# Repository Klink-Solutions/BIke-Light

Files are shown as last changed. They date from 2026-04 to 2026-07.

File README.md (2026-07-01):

# F1® Smart Bike Light

### A universal bike break light designed to improve safety during day and night time operation.

Bike_Light_2026-Apr-03_11-06-38PM-000_CustomizedView57686941933_png

## Description

A F1® rain light inspired bike break light

As an avid biker and lover of F1 I felt why not bring the two together to make me feel a bit faster. While many bikelights that are red and blink do exist; mine does so with function. I found it useful in group rides where you may be caugth off guard by a biker infront of you slowing down. This is where the idea of the adaptive breaklight came into play. Besides the usability for fellow bikers the saftey benifits it provides to you from drivers is enormous. Why do cars need break lights but bikes don't? 

#### Features
  * Adaptive breaking signals your rate of breaking to surrounding drivers and pedestrians 
  * Automatic Day/Night mode
  * Removable for longer battery life and safety
  * Makes your bike look cooler

### Instalation

Mount the bike specific mount to your bikes seat post or bike rack.
The light then securely locks into to the bracket and is easily removable for parking and charging.

* The light automatically goes ito its deepest sleep mode when removed from the bike in this setting this goes it around ~140 (subject to testing) days of operation on a full charge.

* The light automatically adjusts to to local lighting contitions to switch into night mode ( make sure not to cover the sensor for this located at the top to the right of the charging port. 

### Battery life 

* All estimates are subject to testing 

~140 days deep sleep mode

~ 5 hours daytime running

~ 3 hours night time use

## Help

If you are unable to connect the device to your computer to push updates; try holding a magnet near the back to wake up the device from sleep. 

## Authors

Lucas Klemmer  
klinksolutions22@gmail.com

## Version History
* 0.1
    * Initial Release

## Road Map

* Automatic crash detection and warning indicators
* Automatic orientation detection for future features
* Dynamic indicator signals ( might be app controlled but this seems too much of a distraction)
   * If app controlled then potential integration with navigation  

## Repository Contents

This repository contains all components needed for the project:

- CAD files for the housing & universal mount (v2.0) 
- Initial full release code for Bike light 
- Gerber files for PCB manufacturing (v2)
- Supporting project documentation (ReadMe)

## Screenshots




## BOM
[F1 Bike Light-bom.csv](https://github.com/user-attachments/files/26847608/F1.Bike.Light-bom.csv)

<table class="tg"><thead>
  <tr>
    <th class="tg-0lax">Name</th>
    <th class="tg-0lax">Purpose</th>
    <th class="tg-0lax">Quantity</th>
    <th class="tg-0lax">Total Cost (USD)</th>
    <th class="tg-0lax">Link</th>
    <th class="tg-0lax">Distributor</th>
  </tr></thead>
<tbody>
  <tr>
    <td class="tg-0lax">PCBs</td>
    <td class="tg-0lax">$6.30 with current discounts 5 of each of the 2 boards and this price has slow shipping included</td>
    <td class="tg-0lax">10</td>
    <td class="tg-0lax">12.30</td>
    <td class="tg-0lax">https://jlcpcb.com/</td>
    <td class="tg-0lax">JLC PCB</td>
  </tr>
  <tr>
    <td class="tg-0lax">Rechargeable KRL 602030 3.7V 300mAh lithium ion Battery Ultra-Thin 500 Cycles for Wearables IoT Power Tools CE/ KC Certified</td>
    <td class="tg-0lax">Battery</td>
    <td class="tg-0lax">5</td>
    <td class="tg-0lax">6.05</td>
    <td class="tg-0lax">https://www.alibaba.com/product-detail/Rechargeable-KRL-602030-3-7V-300mAh_1600577700959.html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</td>
    <td class="tg-0lax">Alibaba</td>
  </tr>
  <tr>
    <td class="tg-0lax">WP1503SURDK</td>
    <td class="tg-0lax">Ultrabright red LEDs for the main illumination surface</td>
    <td class="tg-0lax">100</td>
    <td class="tg-0lax">13.66</td>
    <td class="tg-0lax">https://www.digikey.ca/en/products/detail/kingbright/WP1503SURDK/16602200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</td>
    <td class="tg-0lax">DigiKey</td>
  </tr>
  <tr>
    <td class="tg-0lax">TEPT4400</td>
    <td class="tg-0lax">Ambient light sensor to enable smart led modes for day vs night time use</td>
    <td class="tg-0lax">5</td>
    <td class="tg-0lax">2.09</td>
    <td class="tg-0lax">https://www.digikey.ca/en/products/detail/vishay-semiconductor-opto-division/TEPT4400/1681191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</td>
    <td class="tg-0lax">Digikey</td>
  </tr>
  <tr>
    <td class="tg-0lax">TLC5927IDBQR</td>
    <td class="tg-0lax">LED driver </td>
    <td class="tg-0lax">5</td>
    <td class="tg-0lax">9.45</td>
    <td class="tg-0lax">https://www.digikey.ca/en/products/detail/texas-instruments/TLC5927IDBQR/1906426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</td>
    <td class="tg-0lax">Digikey</td>
  </tr>
  <tr>
    <td class="tg-0lax">DRV5032FCDBZR</td>
    <td class="tg-0lax">Small SMT bipolar hall effete sensor to act as the wake up for my device</td>
    <td class="tg-0lax">5</td>
    <td class="tg-0lax">1.38</td>
    <td class="tg-0lax">https://www.digikey.ca/en/products/detail/texas-instruments/DRV5032FCDBZR/7173719</td>
    <td class="tg-0lax">DigiKey</td>
  </tr>
  <tr>
    <td class="tg-0lax">ADXL343BCCZ-RL</td>
    <td class="tg-0lax">The main accelerometer ( basically the same as the ADXL 345 i am using for prototyping but with a tiny bit lower sensitivity in exchange for being cheaper) </td>
    <td class="tg-0lax">5</td>
    <td class="tg-0lax">15.87</td>
    <td class="tg-0lax">https://www.digikey.ca/en/products/detail/analog-devices-inc/ADXL343BCCZ-RL/3542841</td>
    <td class="tg-0lax">DigiKey</td>
  </tr>
  <tr>
    <td class="tg-0lax">XIAO ESP32C3</td>
    <td class="tg-0lax">The brains of the break light - Its small size combined with integrated battery charging unit makes it ideal for my application (it is sold in packs of 3 which would be more economical to eventually equip my family with lights of their own </td>
    <td class="tg-0lax">3</td>
    <td class="tg-0lax">13.49</td>
    <td class="tg-0lax">https://www.digikey.ca/en/products/detail/seeed-technology-co-ltd/102010572/24814465</td>
    <td class="tg-0lax">Digikey</td>
  </tr>
</tbody></table>

## License
MIT LIcence

If anyone ends up reproducing this device or making it even bettter I would be happy to see your improvements and add them to the oficial release.

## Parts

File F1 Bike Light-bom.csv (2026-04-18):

Name | Purpose | Quantity | Total Cost (USD) | Link | Distributor
PCBs | $6.30 with current discounts 5 of each of the 2 boards and this price has slow shipping included | 10 | 12.30 | https://jlcpcb.com/ | JLC PCB
Rechargeable KRL 602030 3.7V 300mAh lithium ion Battery Ultra-Thin 500 Cycles for Wearables IoT Power Tools CE/ KC Certified | Battery | 5 | 6.05 | https://www.alibaba.com/product-detail/Rechargeable-KRL-602030-3-7V-300mAh_1600577700959.html | Alibaba
WP1503SURDK | Ultrabright red LEDs for the main illumination surface | 100 | 13.66 | https://www.digikey.ca/en/products/detail/kingbright/WP1503SURDK/16602200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 | DigiKey
TEPT4400 | Ambient light sensor to enable smart led modes for day vs night time use | 5 | 2.09 | https://www.digikey.ca/en/products/detail/vishay-semiconductor-opto-division/TEPT4400/1681191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..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 | Digikey
TLC5927IDBQR | LED driver | 5 | 9.45 | https://www.digikey.ca/en/products/detail/texas-instruments/TLC5927IDBQR/1906426?_gl=1*dl9d99*_up*MQ..*_gs*MQ..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 | Digikey
DRV5032FCDBZR | Small SMT bipolar hall effete sensor to act as the wake up for my device | 5 | 1.38 | https://www.digikey.ca/en/products/detail/texas-instruments/DRV5032FCDBZR/7173719 | DigiKey
ADXL343BCCZ-RL | The main accelerometer ( basically the same as the ADXL 345 i am using for prototyping but with a tiny bit lower sensitivity in exchange for being cheaper) | 5 | 15.87 | https://www.digikey.ca/en/products/detail/analog-devices-inc/ADXL343BCCZ-RL/3542841 | DigiKey
XIAO ESP32C3 | The brains of the break light - Its small size combined with integrated battery charging unit makes it ideal for my application (it is sold in packs of 3 which would be more economical to eventually equip my family with lights of their own | 3 | 13.49 | https://www.digikey.ca/en/products/detail/seeed-technology-co-ltd/102010572/24814465 | Digikey

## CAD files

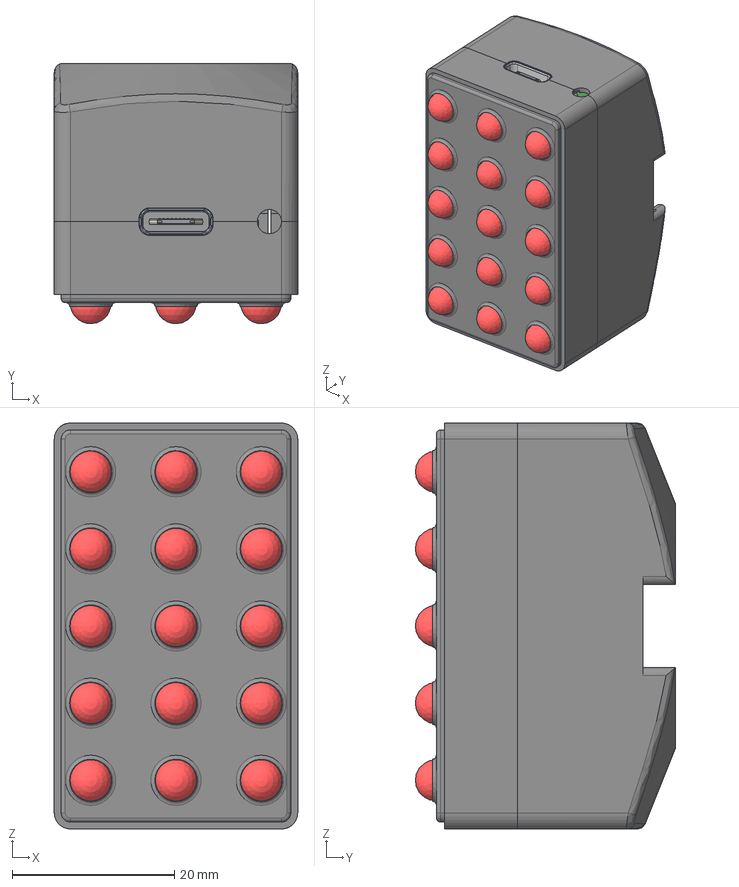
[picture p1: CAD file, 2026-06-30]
CAD/Bike Light case V2.step
30.0 x 32.1 x 50.0 mm
Board
1-copper
64-copper
1-soldermask
64-soldermask
2X08 v2
Board_1
1-copper_1
64-copper_1
1-soldermask_1
64-soldermask_1
9216932.f3d x 5
9216955.f3d
5576557.f3d x 8
JST-2-SMD
BOSS-EXTRUDE14_8_
BOSS-EXTRUDE7_4_
BOSS-EXTRUDE7_3_
BOSS-EXTRUDE14_4_
BOSS-EXTRUDE14_2_
BOSS-EXTRUDE14_11_
BOSS-EXTRUDE7_7_
BOSS-EXTRUDE14_9_
BOSS-EXTRUDE14_3_
BOSS-EXTRUDE14_7_
MIRROR2
BOSS-EXTRUDE14_5_
BOSS-EXTRUDE14_12_
BOSS-EXTRUDE7_8_
BOSS-EXTRUDE7_1_
BOSS-EXTRUDE14_10_
BOSS-EXTRUDE7_9_
BOSS-EXTRUDE14_6_
BOSS-EXTRUDE14_1_
BOSS-EXTRUDE7_6_
BOSS-EXTRUDE7_2_
CUT-EXTRUDE5
BOSS-EXTRUDE7_5_
U.FL Connector v1
Button (1) x 2
Shield
LGA_14 v2
Top Case
93502A111_Symmetrical Heat-Set Inserts for Plastic x 2
Battery
Back Case

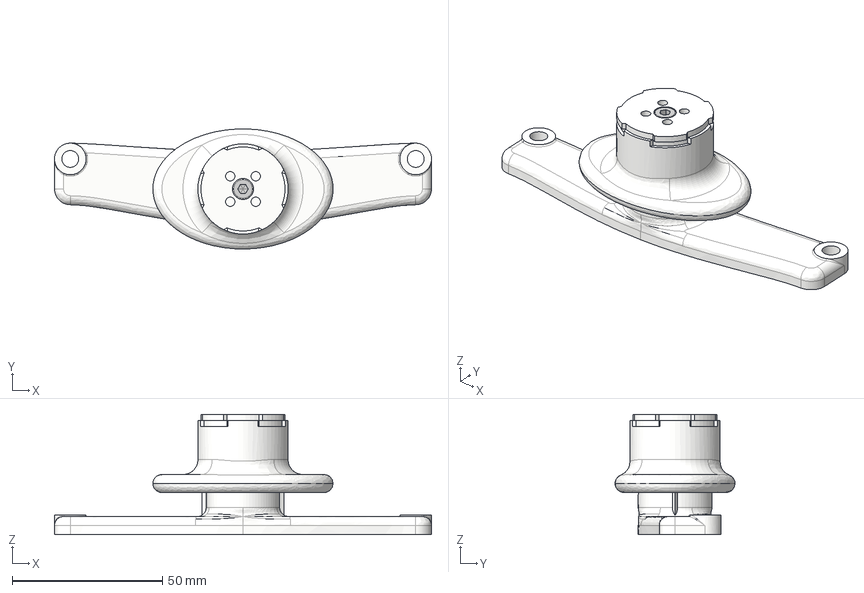
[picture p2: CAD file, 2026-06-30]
CAD/Bike mount v3.step
125.5 x 40.0 x 40.0 mm
Lock Core
Sliding Lock
Stem Clamp
Spring
BSHCS ASME B18.3.1M - M4x0.7 x 20 Steel Grade 2 Plain

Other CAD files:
CAD/Bike Light V2.f3z
CAD/Bike mount.f3z

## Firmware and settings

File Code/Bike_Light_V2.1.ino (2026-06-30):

#include "esp_sleep.h"
#include <Wire.h>
#include <SPI.h>
#include <Adafruit_Sensor.h>
#include <Adafruit_ADXL345_U.h>

// ═══════════════════════════════════════════════════════
//  TUNING 
// ═══════════════════════════════════════════════════════

const int   SMOOTH_SAMPLES  = 10;
const int   JERK_SAMPLES    = 10;
const float JERK_THRESHOLD  = -1.2;
const float ACCEL_THRESHOLD = -0.5;
const int   CONFIRM_MS      = 200;
const int   BRAKE_TIMEOUT   = 400;
const float MAX_ACCEL       = -9.0;
const int   BLINK_SLOW      = 750;
const int   BLINK_FAST      = 50;
const int   SAMPLE_MS       = 20;

// ═══════════════════════════════════════════════════════
//  BATTERY
// ═══════════════════════════════════════════════════════

const float BATTERY_EMPTY_V = 3.2;
const float BATTERY_FULL_V  = 4.2;

// ═══════════════════════════════════════════════════════
//  DAY / NIGHT MODE
// ═══════════════════════════════════════════════════════

const int LIGHT_SENSOR = 3;  // GPIO3 = D1 (TEPT4400 analog out)
float NIGHT_THRESHOLD_LOW  = 0.8;  // drop below this → enter night mode
float NIGHT_THRESHOLD_HIGH = 1.2;  // rise above this → return to day mode

const unsigned long LIGHT_CHECK_INTERVAL_MS = 100; 

int NIGHT_BRIGHTNESS_PERCENT = 40;  //dimming level at night

const unsigned long IDLE_FLASH_INTERVAL_MS = 5000; 
const unsigned long IDLE_FLASH_DURATION_MS = 100;  

const int PWM_FREQ       = 1000; // 1kHz 
const int PWM_RESOLUTION = 8;    // 8-bit = 256 brightness steps

// ═══════════════════════════════════════════════════════
//  PINS
// ═══════════════════════════════════════════════════════

const int TLC_LE    = 21;
const int TLC_OE    = 20;
const int ACCEL_SDA = 6;
const int ACCEL_SCL = 7;
const int HALL      = 5;

// ═══════════════════════════════════════════════════════
//  TLC5927 LED DRIVER — grid mapping
// ═══════════════════════════════════════════════════════

const uint16_t GRID[16] = {
  0x0000, 0x0400, 0x0010, 0x0008, 0x0200, 0x0800, 0x2000, 0x0100,
  0x1000, 0x4000, 0x0080, 0x0020, 0x0001, 0x0040, 0x0004, 0x0002,
};
const uint16_t ALL_ON = 0x7FFF;

uint16_t pos(int p) { return GRID[p]; }

// ─────────────────────────────────────────────
//  Brightness control — PWM on -OE
//
//  -OE is active LOW (LOW = outputs enabled).
//  So the PWM "duty" (HIGH time) must be the
//  INVERSE of the brightness we want:
//    100% bright → OE constantly LOW  → duty 0
//      0% bright → OE constantly HIGH → duty 255
// ─────────────────────────────────────────────
void tlcSetBrightness(int percent) {
  percent = constrain(percent, 0, 100);
  int duty = (int)round((100 - percent) / 100.0 * 255);
  ledcWrite(TLC_OE, duty);
}

void tlcBegin() {
  pinMode(TLC_LE, OUTPUT);
  digitalWrite(TLC_LE, LOW);


  ledcAttach(TLC_OE, PWM_FREQ, PWM_RESOLUTION);
  tlcSetBrightness(0);   

  SPI.begin();
  tlcSend(0x0000);
  tlcSetBrightness(100); // default full brightness; day/night logic adjusts
}

void tlcSend(uint16_t data) {
  SPI.beginTransaction(SPISettings(1000000, MSBFIRST, SPI_MODE0));
  digitalWrite(TLC_LE, LOW);
  SPI.transfer(data >> 8);
  SPI.transfer(data & 0xFF);
  SPI.endTransaction();
  digitalWrite(TLC_LE, HIGH);
  delayMicroseconds(1);
  digitalWrite(TLC_LE, LOW);
}

void tlcAllOn()  { tlcSend(ALL_ON); }
void tlcAllOff() { tlcSend(0x0000); }

uint16_t batteryRowMask(int row) {
  switch (row) {
    case 0: return pos(13) | pos(14) | pos(15);
    case 1: return pos(10) | pos(11) | pos(12);
    case 2: return pos(7)  | pos(8)  | pos(9);
    case 3: return pos(4)  | pos(5)  | pos(6);
    case 4: return pos(1)  | pos(2)  | pos(3);
    default: return 0;
  }
}

int batteryLevel(float voltage) {
  float lvl = mapFloat(voltage, BATTERY_EMPTY_V, BATTERY_FULL_V, 0, 5);
  return constrain((int)round(lvl), 0, 5);
}

void batteryGaugePattern(float voltage) {
  int level = batteryLevel(voltage);
  Serial.println("Battery level: " + String(level) + "/5 ("
                  + String(voltage, 2) + "V)");

  uint16_t pattern = 0;
  for (int row = 0; row < level; row++) {
    pattern |= batteryRowMask(row);
    tlcSend(pattern);
    delay(150);
  }

  if (level == 0) {
    tlcSend(batteryRowMask(0));
    delay(150);
    tlcAllOff();
    delay(150);
    tlcSend(batteryRowMask(0));
  }

  delay(1500);
  tlcAllOff();
}

// ═══════════════════════════════════════════════════════
//  BATTERY VOLTAGE
// ═══════════════════════════════════════════════════════

float readBatteryVoltage() {
  uint32_t total = 0;
  for (int i = 0; i < 16; i++) {
    total += analogReadMilliVolts(A0);
  }
  return 2.0f * total / 16 / 1000.0f;
}

// ═══════════════════════════════════════════════════════
//  AMBIENT LIGHT SENSOR 
// ═══════════════════════════════════════════════════════

float readLightLevel() {
  // average a handful of quick samples to smooth out flicker
  // (passing under power lines, dappled shade, etc.)
  uint32_t total = 0;
  const int samples = 5;
  for (int i = 0; i < samples; i++) {
    total += analogReadMilliVolts(LIGHT_SENSOR);
    delayMicroseconds(200);
  }
  return total / (float)samples / 1000.0f;  // mV → V
}

// ═══════════════════════════════════════════════════════
//  ACCELEROMETER
// ═══════════════════════════════════════════════════════

Adafruit_ADXL345_Unified accel = Adafruit_ADXL345_Unified(1);
RTC_DATA_ATTR int bootCount = 0;

float readAccelZ() {
  sensors_event_t event;
  accel.getEvent(&event);
  return event.acceleration.z;
}

// ═══════════════════════════════════════════════════════
//  ROLLING AVERAGE + LONG-WINDOW JERK
// ═══════════════════════════════════════════════════════

float smoothBuf[SMOOTH_SAMPLES];
float smoothSum  = 0;
int   smoothHead = 0;

void initSmooth(float v) {
  for (int i = 0; i < SMOOTH_SAMPLES; i++) smoothBuf[i] = v;
  smoothSum  = v * SMOOTH_SAMPLES;
  smoothHead = 0;
}

float addSmooth(float v) {
  smoothSum -= smoothBuf[smoothHead];
  smoothBuf[smoothHead] = v;
  smoothSum += v;
  smoothHead = (smoothHead + 1) % SMOOTH_SAMPLES;
  return smoothSum / SMOOTH_SAMPLES;
}

float jerkBuf[JERK_SAMPLES];
int   jerkHead = 0;

void initJerk(float v) {
  for (int i = 0; i < JERK_SAMPLES; i++) jerkBuf[i] = v;
  jerkHead = 0;
}

float computeJerk(float smoothed) {
  float oldest      = jerkBuf[jerkHead];
  jerkBuf[jerkHead] = smoothed;
  jerkHead          = (jerkHead + 1) % JERK_SAMPLES;
  return smoothed - oldest;
}

float mapFloat(float val, float inMin, float inMax,
               float outMin, float outMax) {
  return (val - inMin) * (outMax - outMin) / (inMax - inMin) + outMin;
}

// ═══════════════════════════════════════════════════════
//  SETUP
// ═══════════════════════════════════════════════════════

void setup() {
  Serial.begin(115200);
  delay(200);
  Serial.println("Alive");

  tlcBegin();
  Wire.begin(ACCEL_SDA, ACCEL_SCL);
  pinMode(HALL, INPUT_PULLUP);
  pinMode(A0, INPUT);
  pinMode(LIGHT_SENSOR, INPUT);

  bootCount++;
  Serial.println("Boot: " + String(bootCount));

  // ── Determine day/night before any LED pattern runs ──
  bool isNight = (readLightLevel() < NIGHT_THRESHOLD_LOW);
  tlcSetBrightness(isNight ? NIGHT_BRIGHTNESS_PERCENT : 100);
  Serial.println(isNight ? "Starting in NIGHT mode" : "Starting in DAY mode");

  // ── Battery check on wake ──
  float batteryV = readBatteryVoltage();
  batteryGaugePattern(batteryV);

  // ── ADXL343 ──
  if (!accel.begin()) {
    Serial.println("ADXL343 not found — check wiring");
    while (1);
  }
  accel.setRange(ADXL345_RANGE_4_G);
  accel.writeRegister(0x2D, 0x08);
  Serial.println("ADXL343 ready");

  float firstReading = readAccelZ();
  initSmooth(firstReading);
  initJerk(firstReading);

  // ── State variables ──
  bool          braking          = false;
  bool          jerkFlagged      = false;
  unsigned long confirmStart     = 0;
  bool          confirming       = false;
  unsigned long lastBrakeMs      = 0;
  int           blinkDelay       = BLINK_SLOW;
  bool          ledState         = false;
  unsigned long lastBlink        = 0;
  unsigned long lastSample       = 0;

  unsigned long lastLightCheck   = millis();
  unsigned long lastIdleFlash    = millis();
  bool          idleFlashOn      = false;
  unsigned long idleFlashStart   = 0;

  //Main loop 
  while (digitalRead(HALL) == LOW) {

    unsigned long now = millis();

    // ambient light check (with hysteresis)
    if (now - lastLightCheck >= LIGHT_CHECK_INTERVAL_MS) {
      lastLightCheck = now;
      float lightV  = readLightLevel();
      bool  wasNight = isNight;

      if (!isNight && lightV < NIGHT_THRESHOLD_LOW)  isNight = true;
      if ( isNight && lightV > NIGHT_THRESHOLD_HIGH) isNight = false;

      if (isNight != wasNight) {
        tlcSetBrightness(isNight ? NIGHT_BRIGHTNESS_PERCENT : 100);
        if (!isNight) { tlcAllOff(); idleFlashOn = false; }
        Serial.println(isNight ? ">>> NIGHT MODE" : ">>> DAY MODE");
      }
    }

    //LED control
    if (braking) {
      // Braking always takes priority over the idle flash
      if (now - lastBlink >= (unsigned long)blinkDelay) {
        ledState = !ledState;
        ledState ? tlcAllOn() : tlcAllOff();
        lastBlink = now;
      }
    } else {
      if (ledState) { ledState = false; tlcAllOff(); }

      // Night-only idle flash
      if (isNight) {
        if (!idleFlashOn && now - lastIdleFlash >= IDLE_FLASH_INTERVAL_MS) {
          tlcAllOn();
          idleFlashOn    = true;
          idleFlashStart = now;
          lastIdleFlash  = now;
        }
        if (idleFlashOn && now - idleFlashStart >= IDLE_FLASH_DURATION_MS) {
          tlcAllOff();
          idleFlashOn = false;
        }
      }
    }

    //Sample at fixed rate 
    if (now - lastSample < (unsigned long)SAMPLE_MS) continue;
    lastSample = now;

    float raw      = readAccelZ();
    float smoothed = addSmooth(raw);
    float jerk     = computeJerk(smoothed);

    if (jerk < JERK_THRESHOLD) jerkFlagged = true;

    if (jerkFlagged && smoothed < ACCEL_THRESHOLD) {
      if (!confirming) { confirming = true; confirmStart = now; }
      if (!braking && (now - confirmStart >= (unsigned long)CONFIRM_MS)) {
        braking = true;
        Serial.println(">>> BRAKING START");
      }
    } else {
      confirming  = false;
      jerkFlagged = false;
    }

    if (braking) {
      if (smoothed < ACCEL_THRESHOLD) {
        lastBrakeMs = now;
        float clamped = max(smoothed, MAX_ACCEL);
        blinkDelay = (int)mapFloat(clamped, ACCEL_THRESHOLD, MAX_ACCEL,
                                   BLINK_SLOW, BLINK_FAST);
        blinkDelay = constrain(blinkDelay, BLINK_FAST, BLINK_SLOW);
      }
      if (now - lastBrakeMs > (unsigned long)BRAKE_TIMEOUT) {
        braking = false; jerkFlagged = false; confirming = false;
        Serial.println("<<< BRAKING END");
      }
    }

    Serial.print("Z:"); Serial.print(raw, 2);
    Serial.print(" sm:"); Serial.print(smoothed, 2);
    Serial.print(" jk:"); Serial.print(jerk, 2);
    Serial.print(" B:"); Serial.println(braking ? "YES" : "no");
    Serial.println(" night:" + String(isNight) + " bright:" + String(NIGHT_BRIGHTNESS_PERCENT));
     float Charge = readBatteryVoltage();
    Serial.print("Charge:");Serial.print(Charge);
  }

  //  Magnet removed — shut down and sleep 
  Serial.println("Magnet removed - sleeping in 1 second");
  tlcAllOff();
  tlcSetBrightness(0);              // OE forced HIGH — outputs disabled
  accel.writeRegister(0x2D, 0x0C);
  delay(1000);

  esp_deep_sleep_enable_gpio_wakeup(BIT(HALL), ESP_GPIO_WAKEUP_GPIO_LOW);
  Serial.println("Going to sleep");
  delay(200);
  esp_deep_sleep_start();
}

void loop() {}

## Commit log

2026-04-17 Case V1
2026-04-17 Gerber files V1
2026-04-18 Organized file structure
    [F1 Bike Light-bom.csv]
2026-04-25 Moved BoM to root
    [F1 Bike Light-bom.csv]
2026-06-30 Updated CAD for Initial release
    [Bike Light V2.f3z, Bike Light case V2.step, Bike mount v3.step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]
2026-06-30 Updated Cad and Scematic files to reflect final version
    [Bike Light.f3z, Bike Light.step, LED Plate PCB.brd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]
2026-06-30 Revise repository contents in README
    Updated version numbers and descriptions for CAD, code, and Gerber files.
2026-07-01 Added working prototype image to README
